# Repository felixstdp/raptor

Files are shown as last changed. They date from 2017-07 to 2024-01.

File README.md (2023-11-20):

# raptor
Raptor es un proyecto cuyo propósito es diseñar una serie de chasis de robot velocista. No se trata de un proyecto genérico de robot multipropósito como Sapoconcho sino de un siguelíneas orientado exclusivamente a correr o al menos a intentarlo. El chasis se puede hacer con una base impresa en 3D o bien con una PCB. En los dos casos está preparada para montar en ella módulos (Arduino, Driver de motores, Sensor de líneas…). Este tipo de montaje es muy sencillo para concentrarse en hacer un programa eficiente.

Hay varios chasis diseñados, para Arduino (PCB o impreso, normal y mini) y uno para Raspberry Pi.

https://bricolabs.cc/wiki/proyectos/raptor

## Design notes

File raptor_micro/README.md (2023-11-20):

Versión del Raptor basada en Arduino Pro Micro con chasis impresos en 3D o PCB

- V1.0: Primer modelo, impreso en 3D y PCB basado en el sensor de líneas Pololu QTR-8
- V1.1: Impreso en 3D cambiando la distribución de masas con las pilas hacia atrás.
- V2.0: PCB con la distribución de masas hacia atrás y basado el un sensor de líneas de Aliexpress ('8 sensor lines follow')

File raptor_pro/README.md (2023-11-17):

BOM VSSI: very small scale of integration
- 1x Arduino Nano ATmega328/BLE33/ESP32/STM32
- 2x Driver TA6586
- 2x Encoder Pololu N20
- 2x Motor N20 con eje extendido para encoder
- 1x Sensor IR QTR-8A Pololu
- 1x pulsador + resistencia 10K
- 1x interruptor

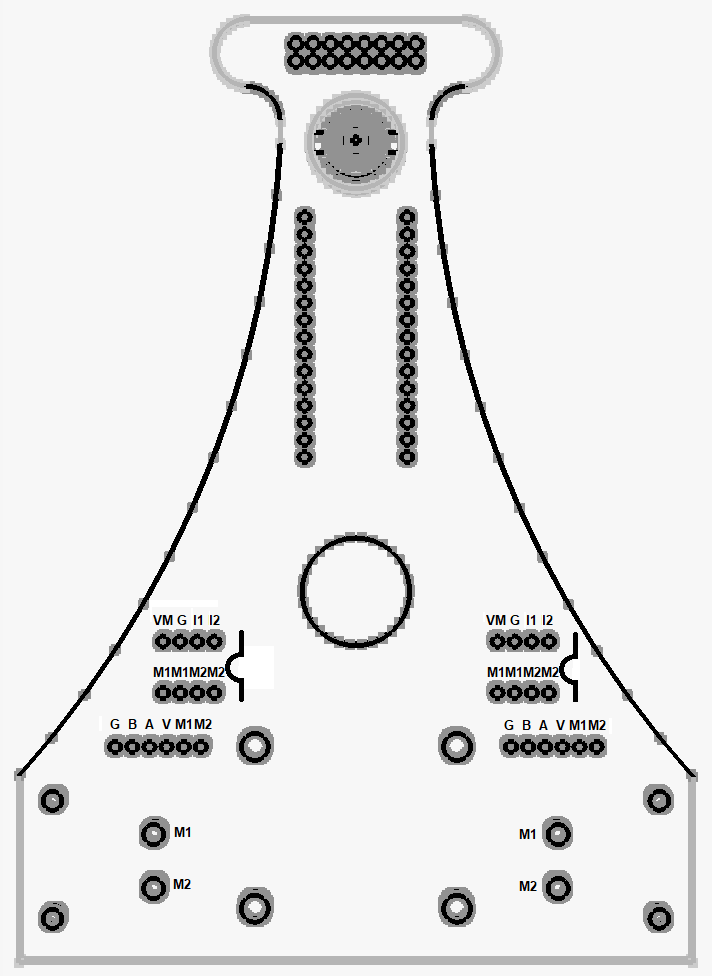
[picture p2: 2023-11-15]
raptor_pro/raptor_pro.png

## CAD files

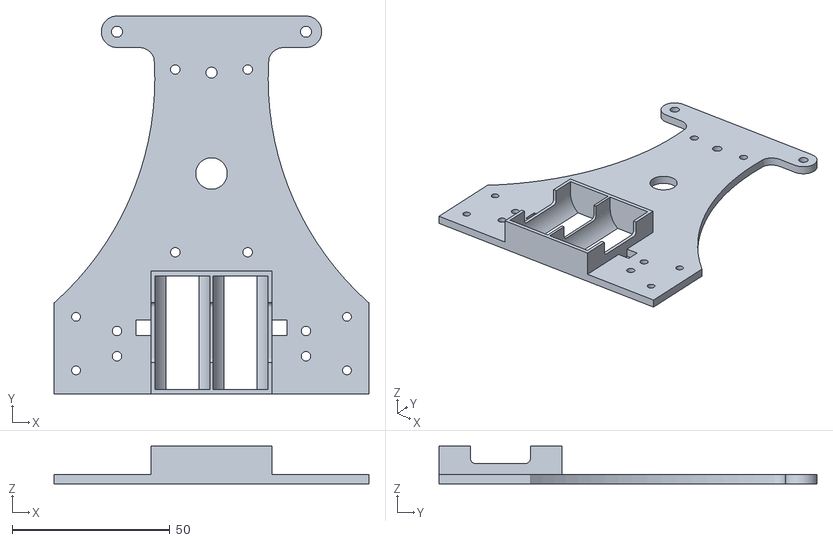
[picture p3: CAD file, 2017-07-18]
raptor_zero/raptor_zero.stl
100.0 x 120.0 x 12.0

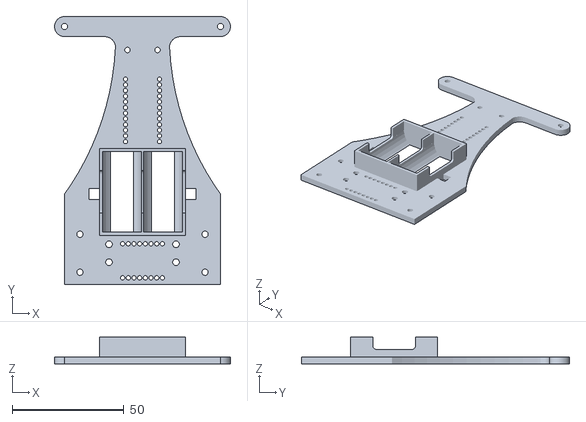
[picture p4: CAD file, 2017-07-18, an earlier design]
raptor_micro/v1.0/raptor.stl
78.8 x 120.0 x 12.0

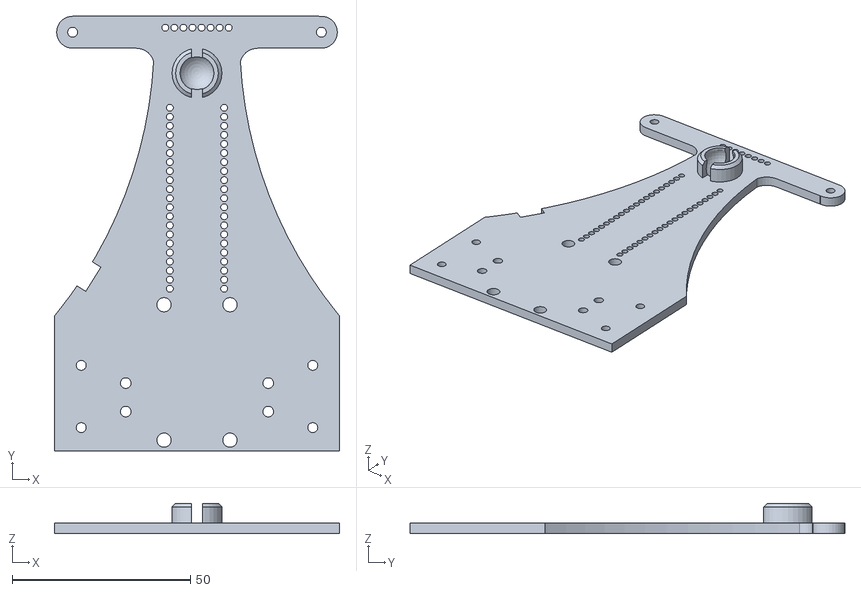
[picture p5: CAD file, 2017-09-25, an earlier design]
raptor_micro/v1.1/raptor_20.stl
80.0 x 122.0 x 8.50

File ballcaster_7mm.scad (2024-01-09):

$fn=60;
difference(){
union(){
cylinder(d=10,h=3.5);
translate([0,0,3.5])sphere(d=10);
hull(){
translate([6.5,0,0])cylinder(d=6,h=2);
translate([-6.5,0,0])cylinder(d=6,h=2);
}
}
translate([0,0,6])cylinder(d=10,h=5);
translate([0,0,4])cylinder(d=7,h=5);
translate([0,0,-5])cylinder(d=10,h=5);
translate([0,0,3.5])sphere(d=7.5);
rotate([0,0,90])translate([0,0,10])
cube(size=[2,11,16],center=true);
translate([-6.5,0,-1])cylinder(d=2.2,h=10);
translate([6.5,0,-1])cylinder(d=2.2,h=10);
}

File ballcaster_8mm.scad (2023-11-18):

$fn=60;
difference(){
union(){
cylinder(d=11,h=5.5);
translate([0,0,5.5])cylinder(r1=5.5, r2=4.5, h=1);
hull(){
translate([6.5,0,0])cylinder(d=6,h=2);
translate([-6.5,0,0])cylinder(d=6,h=2);
}
}
translate([0,0,5])cylinder(d=7.8,h=5);
translate([0,0,4])sphere(d=8.5);
//cylinder(d=8.5,h=4);
rotate([0,0,90])translate([0,0,10])
cube(size=[2,11,16],center=true);
translate([-6.5,0,-1])cylinder(d=2.2,h=10);
translate([6.5,0,-1])cylinder(d=2.2,h=10);
translate([-6.5,0,2])cylinder(d=4.5,h=10,$fn=6);
translate([6.5,0,2])cylinder(d=4.5,h=10,$fn=6);
}

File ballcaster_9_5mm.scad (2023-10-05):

$fn=120;

%translate([0,0,5])sphere(d=10);
 
 // soporte bola
 
difference(){
union(){
cylinder(d=13.5,h=7);
translate([0,0,7])cylinder(d1=13.5, d2=11.5, h=1);
hull(){ 
translate([-6.5,0,0])cylinder(d=6,h=1.5);
translate([6.5,0,0])cylinder(d=6,h=1.5);
}
}
translate([0,0,5])cylinder(d=9.5,h=25);
translate([0,0,5])sphere(d=10.5);
translate([0,0,10.5])cube(size=[15,3,16],center=true);
translate([-6.5,0,-1])cylinder(d=2.2,h=10);
translate([6.5,0,-1])cylinder(d=2.2,h=10);
translate([-6.5,0,1.5])rotate([0,0,30])
cylinder(d=4,h=10,$fn=6);
translate([6.5,0,1.5])rotate([0,0,30])
cylinder(d=4,h=10,$fn=6);
}

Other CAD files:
rear_wing_2.scad
raptor_micro/v1.0/raptor.scad
raptor_micro/v1.1/raptor_20_sensor_chino.scad
raptor_micro/v1.1/raptor_20_sensor_pololu.scad
raptor_micro/v2.0/chassis.scad
raptor_micro/v2.0/chassis_2.scad
raptor_micro/v2.0/chassis_3.scad
raptor_micro/v2.0/chassis_4.scad
raptor_mini/raptor 2.0/raptor20.scad
raptor_mini/raptor 2.0/raptor_20.scad
raptor_mini/raptor 2.0/raptor_20_mjkdz.scad
raptor_pro/evo/raptor_pro_v1.scad
raptor_pro/evo/raptor_pro_v2.scad
raptor_pro/evo/raptor_pro_v3.scad
raptor_pro/evo/raptor_pro_v4.scad
raptor_pro/evo/raptor_pro_v5.scad
raptor_pro/evo/raptor_pro_v6.scad
raptor_pro/evo/raptor_pro_v7.scad
raptor_pro/evo/raptor_pro_v8.scad
raptor_pro/evo/soporte_cables.scad
raptor_pro/soporte_turbina.scad
raptor_pro/turbina.scad
raptor_pro/turbina_2.scad
raptor_zero/raptor_zero.scad

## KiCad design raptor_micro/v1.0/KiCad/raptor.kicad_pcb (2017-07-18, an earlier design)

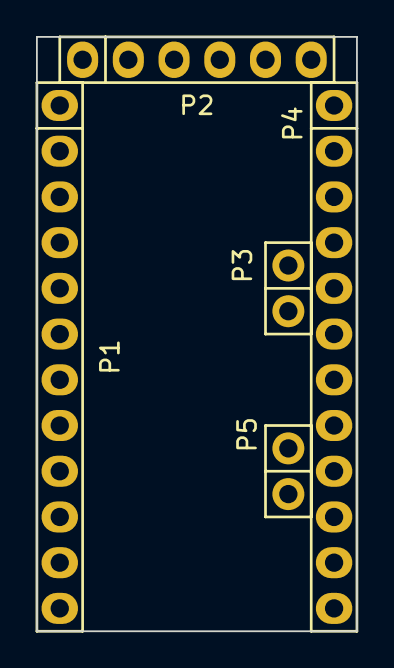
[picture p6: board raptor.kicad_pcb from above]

Board: 2 copper layers, 17.8 x 33.0 mm, 5 parts (0 on the bottom side), 5 nets, no tracks yet.

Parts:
P1: Digital; Socket_Strip_Arduino_1x12
P2: COM; Socket_Strip_Arduino_1x06
P3, P5: ADC; Socket_Strip_Arduino_1x02
P4: Analog; Socket_Strip_Arduino_1x12

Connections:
/0(Rx): P1.2, P2.3
/1(Tx): P1.1, P2.2
/Reset: P1.3, P4.3
GND: P1.4, P2.5, P2.6, P4.2
VCC: P2.4, P4.4

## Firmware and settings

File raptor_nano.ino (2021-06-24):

// Arduino Nano

// TB6612 driver pinout
const int STBY = 6; // standby
const int PWMA = 9; // speed and direction control motor A (left)
const int AIN1 = 8;
const int AIN2 = 7;
const int PWMB = 10; // speed and direction control motor B (right)
const int BIN1 = 11;
const int BIN2 = 12;

void setup() {
  pinMode(STBY,OUTPUT);
  pinMode(PWMA,OUTPUT);
  pinMode(AIN1,OUTPUT);
  pinMode(AIN2,OUTPUT);
  pinMode(PWMB,OUTPUT);
  pinMode(BIN1,OUTPUT);
  pinMode(BIN2,OUTPUT);
}

void loop()
{
  drive(200,200,1000); // forward move
  drive(-200,-200,1000); // reverse move
  drive(200,-200,1000); // rotate right
  drive(-200,200,1000); // rotate left
}

void drive(int L, int R, int t) // speed for wheels Left and Right, positive is forward,time in microseconds
{
  L=constrain(L,-255,255); // avoid PWM overflow
  R=constrain(R,-255,255);
  
  digitalWrite(AIN1, L<0); // switch < and >= if left wheel doesnt spin as expected
  digitalWrite(AIN2, L>=0);
  analogWrite(PWMA, abs(L));
  
  digitalWrite(BIN1, R<0); // switch < and >= if left wheel doesnt spin as expected
  digitalWrite(BIN2, R>=0);
  analogWrite(PWMB, abs(R));
  
  delay(t);
}

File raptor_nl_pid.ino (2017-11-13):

// followline PID algorithm for Bricolabs Raptor robot
// Arduino Pro Micro, TB6612 driver, Pololu QTR-8 sensor

// TB6612 driver pinout
const int STBY = 15; // standby
const int PWMA = 5; // speed and direction control motor A (left)
const int AIN1 = 2;
const int AIN2 = 3;
const int PWMB = 10; // speed and direction control motor B (right)
const int BIN1 = 14;
const int BIN2 = 16;

// Pololu QTR-8A analog array readout
#include <QTRSensors.h>
QTRSensorsAnalog qtra((unsigned char[]) {6, 7, 8, 9, 0, 1, 2, 3 }, 8);
unsigned int IR[8];

// parameters and variables for non linear PID
const int vmin=80;
const int vmax=150;
const float kp=.015;
const float ki=0.0003;
const float kd=0.2;
const float kv=0.07;
int p,d,u,vbase;
long i=0;
int p_old=0;

void setup() {
}

void loop()
{
  digitalWrite(STBY, HIGH);
  
  qtra.read(IR); // read raw sensor values
  
  p = -7*IR[0]-5*IR[1]-3*IR[2]-IR[3]+IR[4]+3*IR[5]+5*IR[6]+7*IR[7];
  i=i+p;
  d=p-p_old;
  p_old=p;
  if ((p*i)<0) i=0;  // integral windup

  u=kp*p+ki*i+kd*d;
  vbase=vmin+(vmax-vmin)*exp(-kv*abs(kp*p));
  drive(vbase+u,vbase-u);
 
}

void drive(int L, int R) // speed for wheels Left and Right, positive is forward
{
  L=constrain(L,-255,255); // avoid PWM overflow
  R=constrain(R,-255,255);
  
  digitalWrite(AIN1, L<0); // switch < and >= if left wheel doesnt spin as expected
  digitalWrite(AIN2, L>=0);
  analogWrite(PWMA, abs(L));
  
  digitalWrite(BIN1, R<0); // switch < and >= if left wheel doesnt spin as expected
  digitalWrite(BIN2, R>=0);
  analogWrite(PWMB, abs(R));
}

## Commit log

2023-10-20 Update and rename raptor_20_mjkdz.scad to raptor_20_sensor_chino.scad
    [raptor_20_sensor_chino.scad]
2023-10-20 Update and rename raptor_20.scad to raptor_20_sensor_pololu.scad
    [raptor_20_sensor_pololu.scad]
2023-11-17 Update and rename raptor_pro_v2 to raptor_pro_v2.scad
    [raptor_pro_v2.scad]
